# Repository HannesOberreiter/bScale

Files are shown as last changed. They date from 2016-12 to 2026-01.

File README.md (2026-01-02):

# bScale for app.btree.at

Small Arduino project for a DIY beehive scale, with SIM900 for connection to webservice. This project is made to work with the webapplication **[btree.at](https://www.btree.at/)**, an online database for beekeeper but you can use any webservice you want.

## New improved build from Piotr from Poland

Update: 2021-01-29, Piotr did again an update. His setup and code now includes a thermal compensation for drift of weight scale due to shift of temperature, see open issue for more details [issues/7#issue-796765492](https://github.com/HannesOberreiter/bScale/issues/7#issue-796765492) and new ino file: [piotr_SHTC3.ino](arduino/piotr_SHTC3.ino).

***Please see following markdown with description of a improved build version for the beescale:
[Piotr BeeScale](PiotrBeeScale.md).***

Big chances are the separation of the battery unit from the UNO and SIM module and a higher voltage battery storage and solar charging in mind.

Thanks to [@PiotrBeeScale](https://github.com/PiotrBeeScale)

### Hardware

* UNO R3 MEGA ([AliExpress ca. € 2.70](http://de.aliexpress.com/item/high-quality-UNO-R3-MEGA328P-for-Arduino-UNO-R3-NO-USB-CABLE/32350449393.html))
* SIMCON SIM900 Shield (Important with power up pin!) ([Ebay China € 21.99](http://www.ebay.at/itm/SIMCOM-SIM900-Quad-band-GSM-GPRS-Shield-Development-Board-for-Arduino-/231857925209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))
* atTiny85 + Base ([Ebay ca. € 6,00 ](http://www.ebay.at/itm/3x-Atmel-ATTiny85-20PU-und-3x-DIL-Sockel-/251833156761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))
* N-Mosfet ([Ebay ca. < € 1,00](http://www.ebay.at/itm/5-BUZ11-Fairchild-MOSFET-Transistor-50V-30A-75W-0-04R-854773-/311597076091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))
* HX711 Sensor ([Ebay China < € 1,00](http://www.ebay.at/itm/5PCS-Weighing-Sensor-AD-Module-Dual-channel-24-bit-A-D-Conversion-HX711-Shieding-/272298400315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))
* < 200kg platform load cell ([AliExpress ca. € 17,00](http://de.aliexpress.com/item/1PCS-X-100KG-150KG-electronic-platform-scale-load-cell-pressure-balanced-cantilever-load-weight-sensor/1743007676.html))
* LPDP 5V ([Ebay ca. € 1,00](http://www.ebay.at/itm/LP2950CZ-5-0-LowDrop-Spannungsregler-5V-0-1A-TO92-/112028436978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))

and battery case, batteries, resistors, jumper wire, scale plattform, Total cost was under € 100,00.

### Dirty Build:
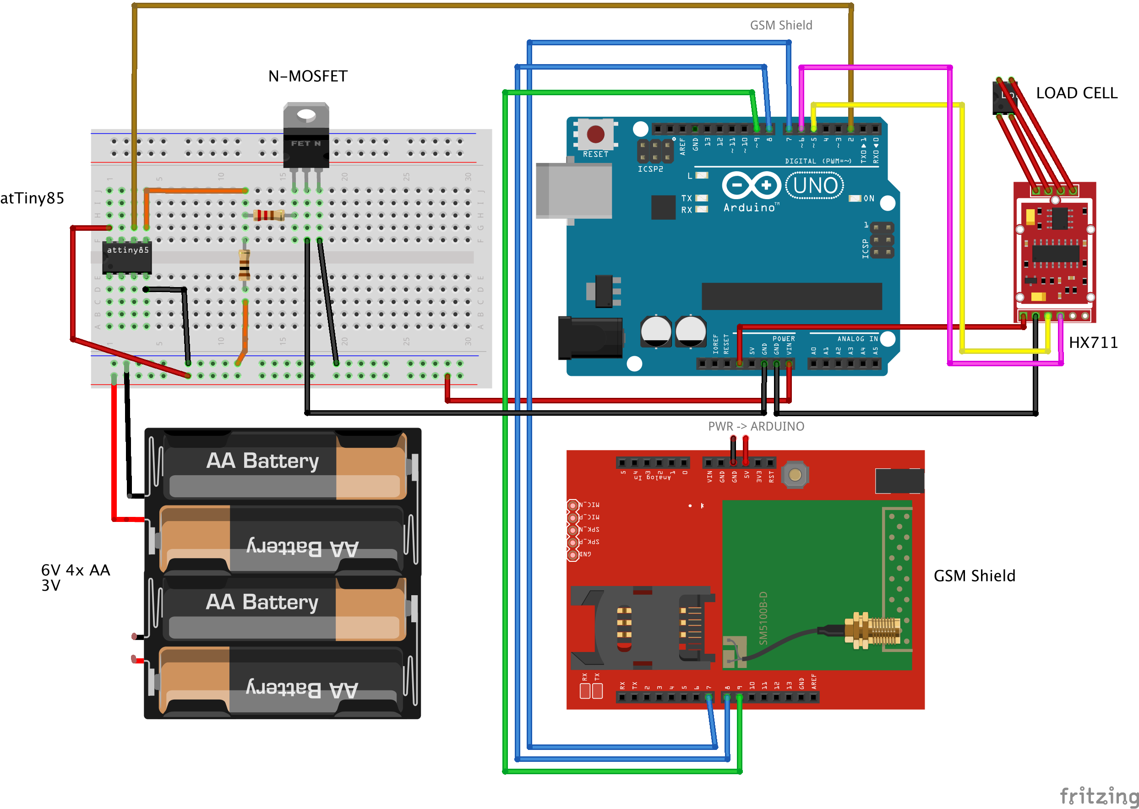
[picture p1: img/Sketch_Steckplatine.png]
Fritzing Sketch Fritzing


### How does / should it work?

UNO will collect data from sensors and send them to the shield. Uno forwards the data to SIM900, which connects to the webservice.
atTiny85 is a simple counter, it will send each 120 minutes a pulse to the N-Mosfet gate. The Mosfet will open circuit to activate Uno.

The UNO will tell the atTiny85 when the sending was completed. If the sending is not completed within 60 seconds, the atTiny will shutdown the UNO even it is not completed (No connection to internet etc.).

### Sensor Reading

For the Sensor reading you need to install the DHT Library and because a bug in Version 1.3 in this library you also need to install the [Adafruid Unified Sensor Library.](https://cloud.githubusercontent.com/assets/181073/21481640/5e14ebd8-cb6a-11e6-972e-c4b4efda6ad1.png)

### The webservice

You can send the data to the beekeeping application (not free) [btree.at](https://www.btree.at/). There the data will be shown in tables and statistics. But you can change the webservice to any you want.

### Videos

**German:**

* [b.tree Open Source Bienenstockwaage kalibrieren ](https://www.youtube.com/watch?v=fo4yXhe6Qlo)
* [b.tree Open Source Bienenstockwaage atTiny85 programmieren ](https://youtu.be/5xHgviWt0F4)

### Images (more in img folder!)

**SIM900 Power On Pin**

On some SIM900 Modules the power up pin is not connected and you need to smolder the right position. Please see your specific Module description.
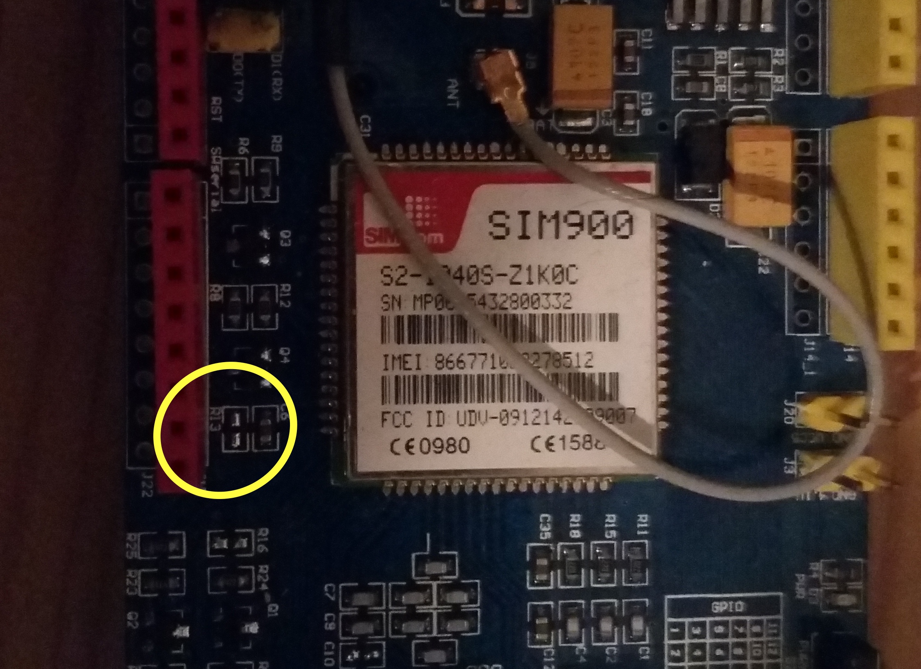
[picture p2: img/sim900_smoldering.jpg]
SIM900 smoldering


If you use a single weight cell like me, the whole build is a little bit "shaky". To prevent to much bending on the iron bars I added this screws on all four sides with just milimeters of space.
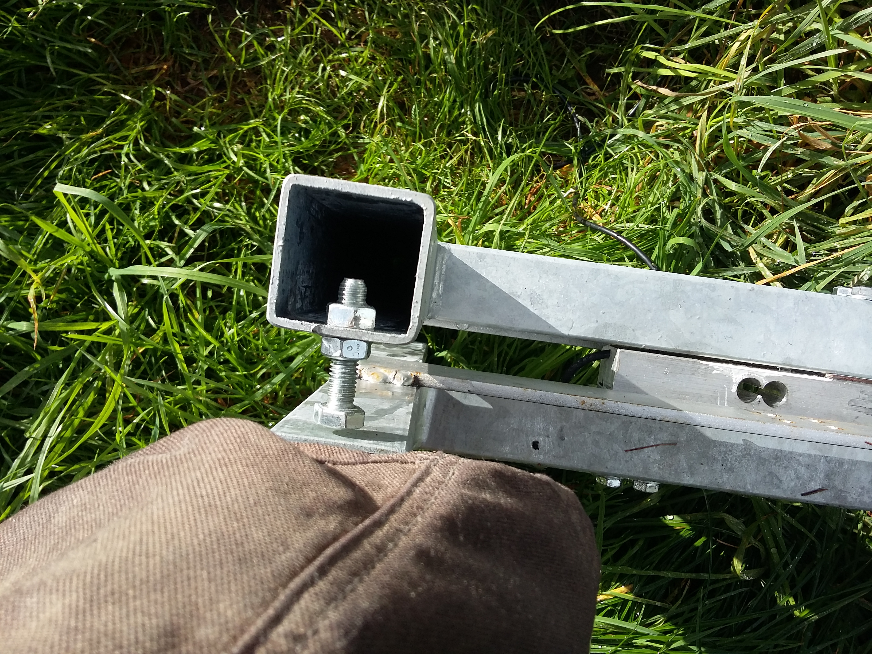
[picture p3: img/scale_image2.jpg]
Screws


### Special thanks to

Andi_H from bienenforum.com for the idea and lots of code pieces

bodge awesome HX711.h library <https://github.com/bogde/HX711>

Nathan Seidle SparkFun Electronics for calibrate code <https://github.com/sparkfun/HX711-Load-Cell-Amplifier>

My father for help with the electronics.

### Tests

* 2016-08-30 First field test the battery would handle 10 days. With each 30 minutes open the mosfet for 1 minute. Changed the code to only open the gate each 2 hours and the UNO will tell the atTiny when it is finsihed. Lets see how much of an improvment this will give us. Upload works fine, data also seems ok, Hannes.
* 2016-10-18 Second field test, with the new code (each 2 hours) did the battery last for 50 days. The battery still has power but not enough to open the GSM connection. I will try now instead of alkaline batteries lithium batteries. They should work better with the spike of energy needed for the GSM connection

### License
GNU GPLv3

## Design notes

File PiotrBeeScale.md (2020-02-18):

# Introduction

This version is a improved build of the bee scale, thanks to Piotr. 

He uses a 5V battery with solar charging in mind and separated the whole battery part from the Arduino and SIM Module for a more safety and cleaner build. 

Following is his build description. 

# Sample weight frame

It was made of a closed profile with a 30x30 mm square section. The weight sensor mounting place was made of a flat bar with a 4 mm diameter. The whole is welded with a MIG / MAG welder. In the lower part of the frame four M8 nuts are welded. Leveling feet are screwed into these nuts. The fastening of the hermetic boxes was made of a cold-bent angle 20x20x2 mm. There is a gap of about 15 mm between the weight segments. The gap is sufficient. The whole was painted with anti-corrosive paint. The frame dimensions have been chosen for the Dadant beehive type.

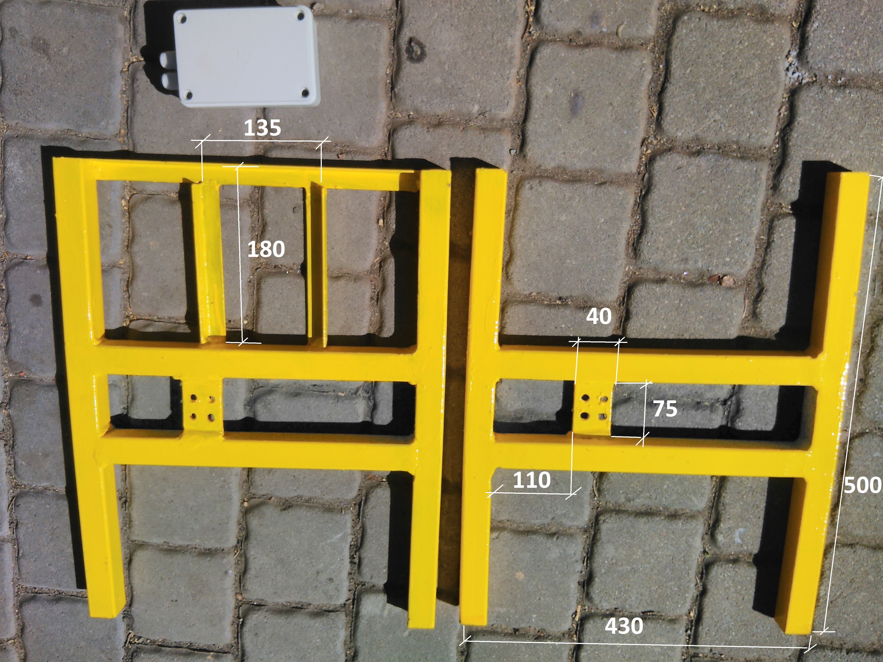
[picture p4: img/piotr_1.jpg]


# View of the scale with mounted hermetic electric boxes
View of the scale with mounted hermetic electric boxes.
Two hermetic electrical boxes were mounted on the frame of the frame. You can use double-sided adhesive tape for this. One has an arduino, mounting plate, HX711 chip, SIM900 and internal antenna. The other has a 6V battery and a solar charging system. Cables enter the boxes through PG-7 glands.

Hermetic electric box, type: S-Box 216 - 120x80x50 - IP65

The weight sensor was attached to the frame with M8x35 mm Allen screws on washers.

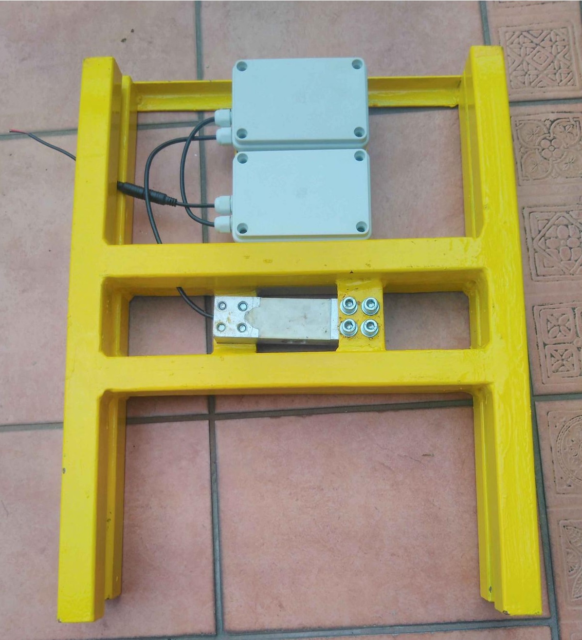
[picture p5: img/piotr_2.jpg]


# Arrangement of elements in electrical boxes

1. Board with HX-711 chip. Fastened to the side wall with double-sided adhesive tape.
2. Arduino Uno R3 board
3. Mounting plate - "Proto Screw Shield Assembled Prototype Terminal Expansion Board Module For Arduino IO I / O UNO R3 MEGA2560 Double Side SMT Solder"
4. Internal antenna for SIM900 - "WIFI 2.4G 3dbi PCB Antenna IPX IPEX WLAN Laptop Bluetooth Zigbee Wireless Module SIM900"
5. SIM900 direct power supply - "2.1mm x 5.5mm Male Plug Right Angle L Jack DC Power Connector"
6. input for power supply from solar panel - "5.5x2.1mm Plug DC male or Female Cable Wire Connector"
7. battery voltage regulator - "LM2596S DC-DC LM2577S Step Up Down Boost Buck Voltage Power Converter Module Non-isolated Constant Current Board 15W 3A"
8. AGM gel battery:
* Voltage: 6V
* Capacity: 1.3Ah
* Height - 51mm
* Length - 96mm
* Width - 24mm

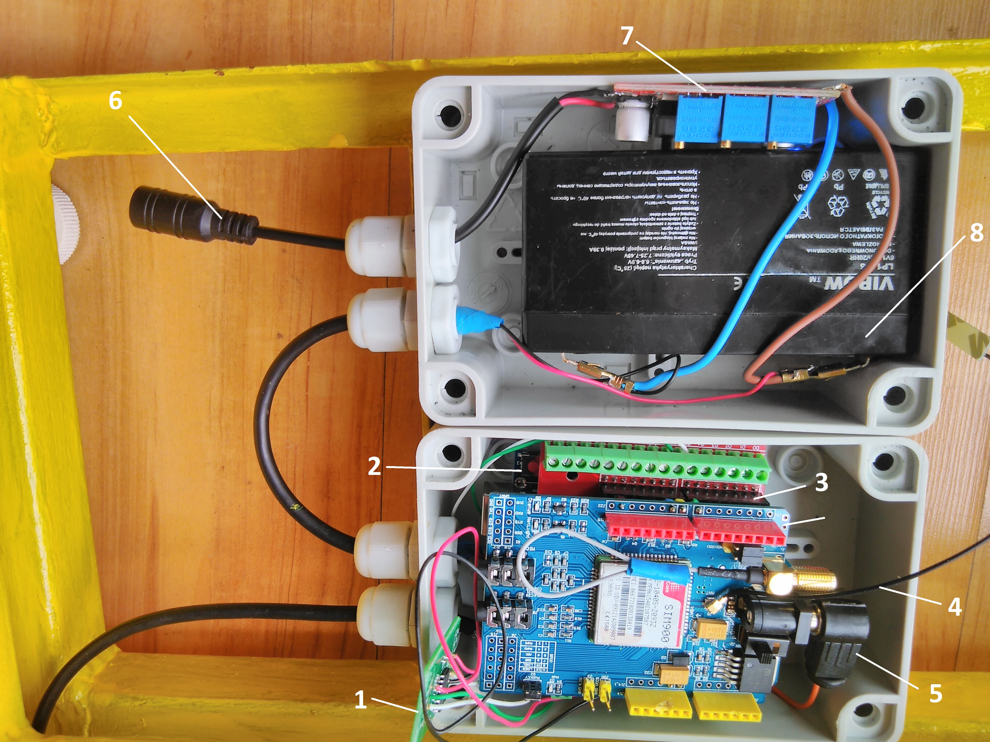
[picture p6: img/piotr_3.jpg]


# Screw Shield

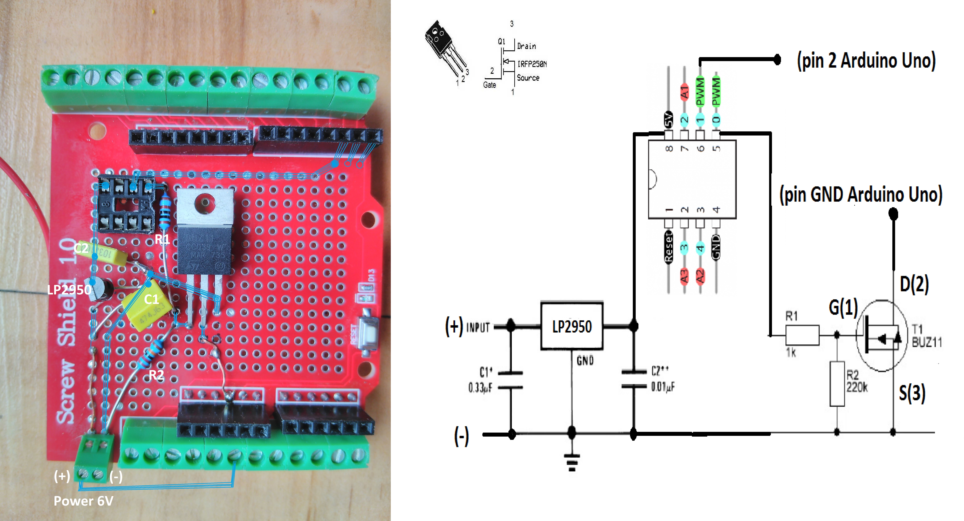
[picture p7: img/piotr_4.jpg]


# SIM900 plate - extra pins

1, 2 - Pins that need to be soldered to the SIM900 board

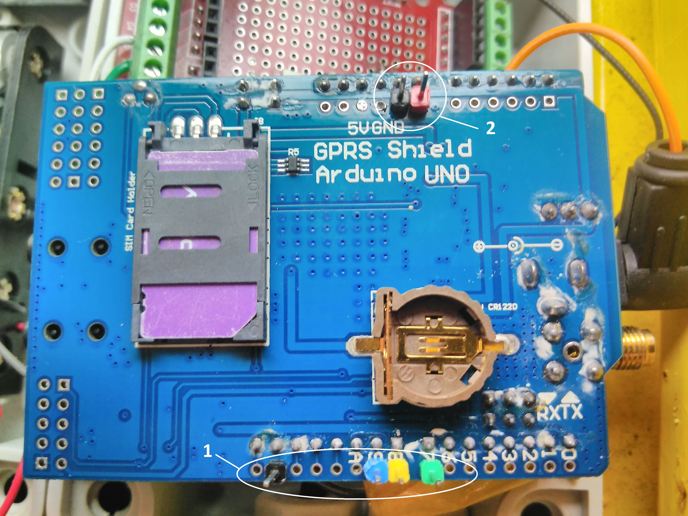
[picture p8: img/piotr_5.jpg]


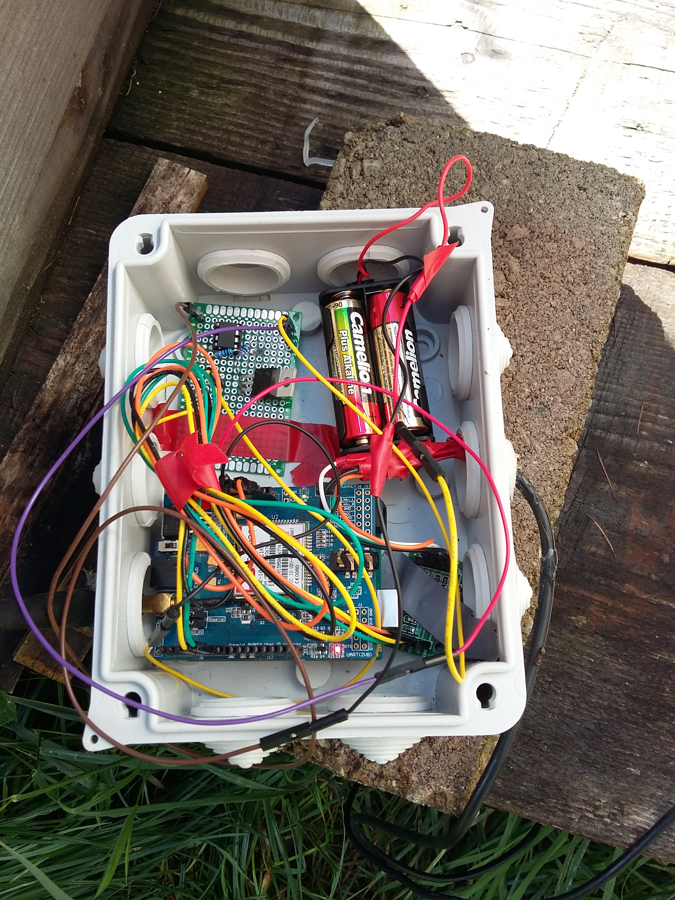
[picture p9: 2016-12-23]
img/scale_image4.jpg

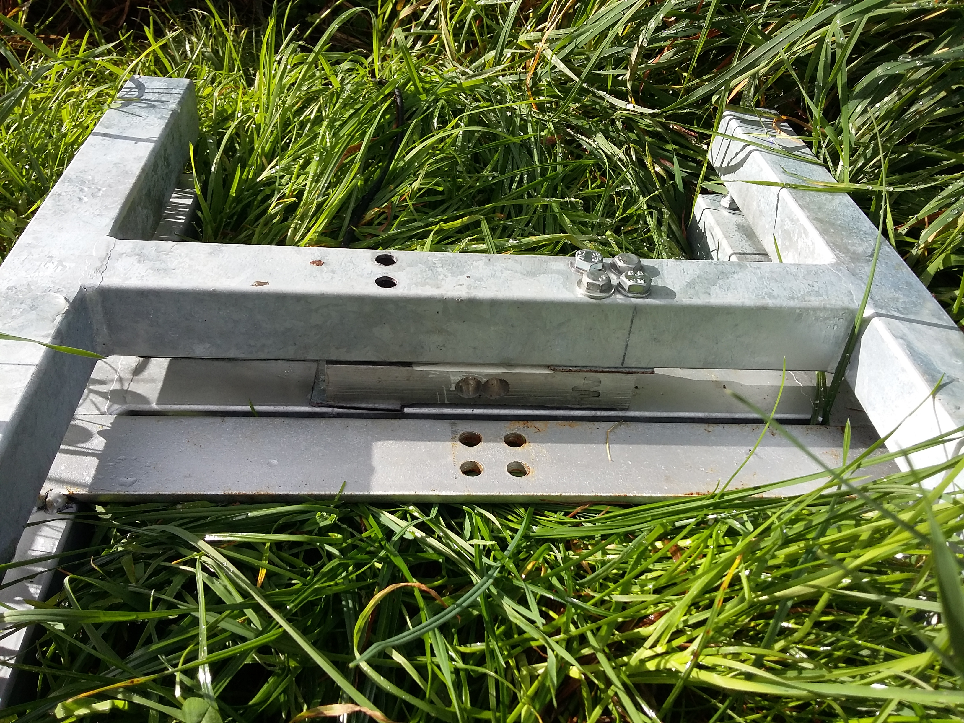
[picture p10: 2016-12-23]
img/scale_image1.jpg

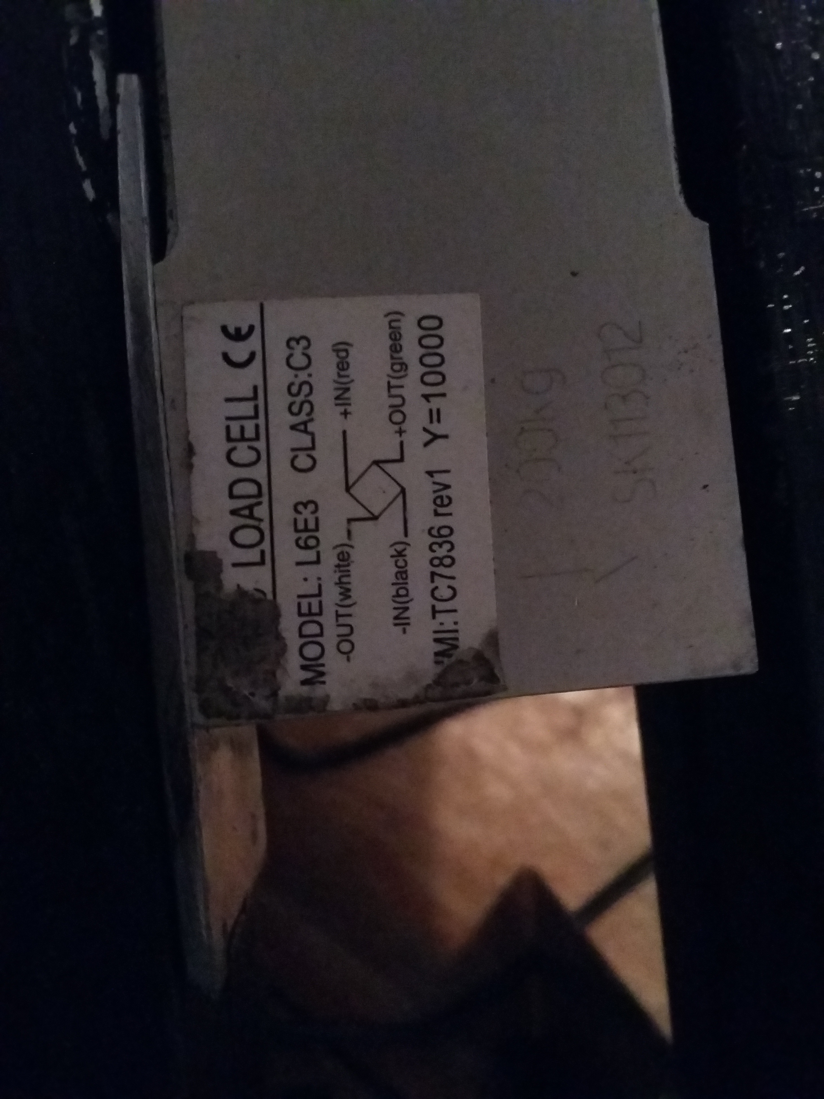
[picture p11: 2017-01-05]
img/load_cell_wires.jpg

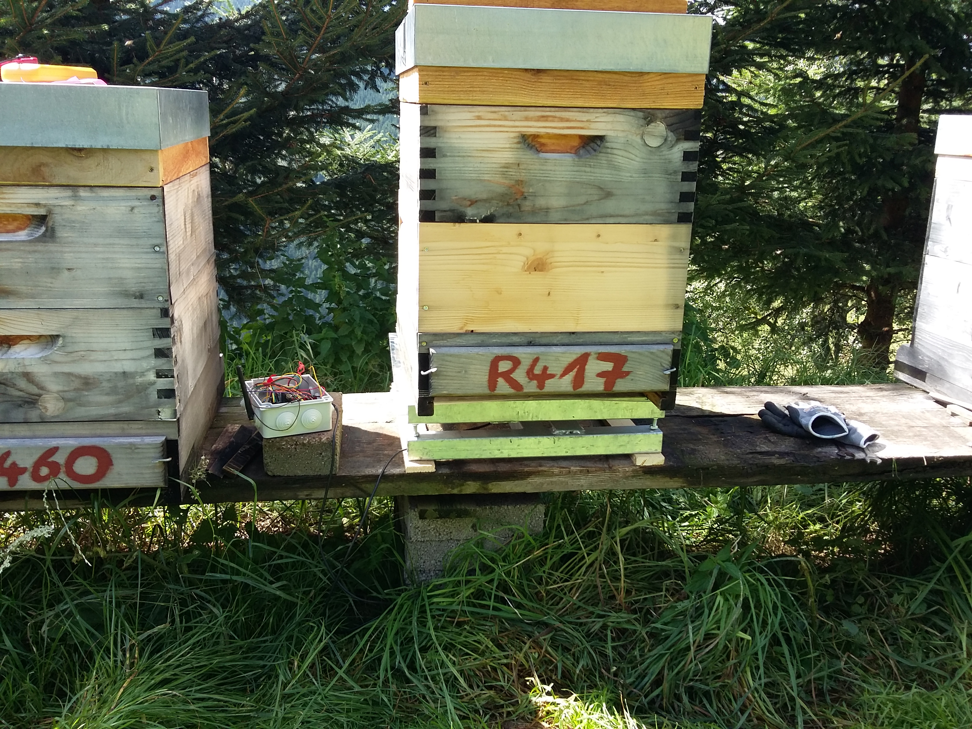
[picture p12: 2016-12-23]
img/scale_image3.jpg

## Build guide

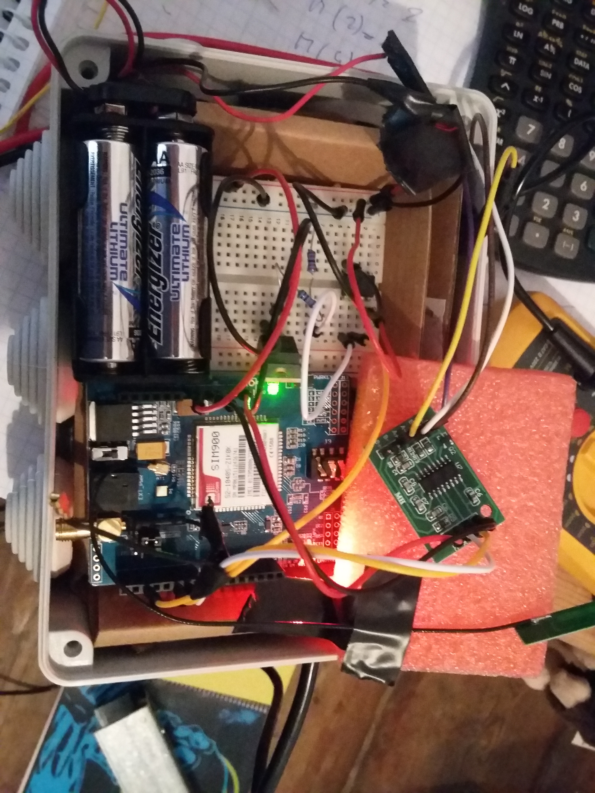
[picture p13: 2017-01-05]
img/inside_build.jpg

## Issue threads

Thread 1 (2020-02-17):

Sample weight frame

PiotrBeeScale, 2020-02-17:
Sample weight frame.
It was made of a closed profile with a 30x30 mm square section. The weight sensor mounting place was made of a flat bar with a 4 mm diameter. The whole is welded with a MIG / MAG welder. In the lower part of the frame four M8 nuts are welded. Leveling feet are screwed into these nuts. The fastening of the hermetic boxes was made of a cold-bent angle 20x20x2 mm.
There is a gap of about 15 mm between the weight segments. The gap is sufficient. The whole was painted with anti-corrosive paint.
The frame dimensions have been chosen for the Dadant beehive type.

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

Closed 2020-02-18.

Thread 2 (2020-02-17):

View of the scale with mounted hermetic electric boxes

PiotrBeeScale, 2020-02-17:
View of the scale with mounted hermetic electric boxes.
Two hermetic electrical boxes were mounted on the frame of the frame. You can use double-sided adhesive tape for this. One has an arduino, mounting plate, HX711 chip, SIM900 and internal antenna. The other has a 6V battery and a solar charging system. Cables enter the boxes through PG-7 glands.
Hermetic electric box, type: S-Box 216 - 120x80x50 - IP65
The weight sensor was attached to the frame with M8x35 mm Allen screws on washers.

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

Closed 2020-02-18.

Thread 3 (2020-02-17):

Arrangement of elements in electrical boxes

PiotrBeeScale, 2020-02-17:
1 - Board with HX-711 chip. Fastened to the side wall with double-sided adhesive tape.
2 - Arduino Uno R3 board
3 - Mounting plate - "Proto Screw Shield Assembled Prototype Terminal Expansion Board Module For Arduino IO I / O UNO R3 MEGA2560 Double Side SMT Solder"
4 - Internal antenna for SIM900 - "WIFI 2.4G 3dbi PCB Antenna IPX IPEX WLAN Laptop Bluetooth Zigbee Wireless Module SIM900"
5 - SIM900 direct power supply - "2.1mm x 5.5mm Male Plug Right Angle L Jack DC Power Connector"
6 - input for power supply from solar panel - "5.5x2.1mm Plug DC male or Female Cable Wire Connector"
7 - battery voltage regulator - "LM2596S DC-DC LM2577S Step Up Down Boost Buck Voltage Power Converter Module Non-isolated Constant Current Board 15W 3A"
8 - AGM gel battery:
• Voltage: 6V
• Capacity: 1.3Ah
• Height - 51mm
• Length - 96mm
• Width - 24mm

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

Closed 2020-02-18.

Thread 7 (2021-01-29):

Thermal compensation of the measurement

PiotrBeeScale, 2021-01-29:
The temperature influences the balance indications. When the temperature changes, the weight reading changes, even though the load on the scale has not changed.
Therefore, temperature measurement and balance reading compensation are required.
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
Need to install a temperature sensor. I chose SHTC3.
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
Library:
https://www.14core.com/wiring-sensirion-i2c-shwx-shtcx-sht3x-temperature-humidity-sensor/

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

**Wiring sketch**
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

The comparison of the temperature and weight measurements shows that the correction is possible with a linear function y=ax+b.
Here is an excel sheet with measurements and a calculated correction.
[Kompensacja temperaturowa.xlsx](https://github.com/HannesOberreiter/bScale/files/5893111/Kompensacja.temperaturowa.xlsx)
**Arduino code changes :**

[Arduino_SHTC3.zip](https://github.com/HannesOberreiter/bScale/files/5893196/Arduino_SHTC3.zip)

HannesOberreiter, 2021-01-29:
Hi Piotr,

hope you doing well. Added the information for your new setup to the repo. I leave the Issue open for others to look at.

I stopped working with hive scales, but I'm happy to see that you still work with it.

Cheers
Hannes

PiotrBeeScale, 2021-02-03:
Hello Hannes

I have noticed that you are tackling more serious projects. I am continuing to work on the scale as it has attracted interest on the beekeeping forum. By the way, there was a problem with the effect of temperature on the scale readings. The differences were so significant that a correction had to be worked out. I am pleased that new people have joined the topic. I hope that they will actively participate in the development of this project, the design of which has impressed me. Especially because of the power saving by using ATtiny85. An app for Android and iOS would be useful for this scale.

 Wishing you good health and further success
Piotr

HannesOberreiter, 2021-02-04:
Hello Piotr,

thats good to hear. Yes, scale drift by temperature is often overlooked even in professional sold bee hive scales.

I reduced the amount of colonies, as the last few years I had a really bad harvest (2x lots of melezitose honey). Now I only do beekeeping as hobby anymore and try to find other ways to get some income for living.

As for the App I'm working on making my application open source (rewriting code and remove external proprietary licences). This may help other beekeepers to host their own server and application in combination in combination with their own hive scale, but this project will take at least another year time, as I only can work on it on my free time.

Cheers
Hannes

PiotrBeeScale, 2021-02-07:
Hello Hannes,
It is sad when there are losses in bees due to unfavorable natural conditions.
But seeing how well you write programs, I believe you have no trouble finding a job.
I am not a programmer, I dealt a bit with database administration. I also have a bit of an idea about electronics. Currently, I am developing scripts that analyze data from beekeeping scales so that event notifications are sent to gmail.
I am very glad that you are planning to provide a smartphone application.
Cheers
Piotr

Closed 2021-02-07.

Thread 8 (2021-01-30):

saving the measurement for shipment

Viator325, 2021-01-30:
Its possible to change the cod to:
-do a measurement of weight, temperature itp. on indicated time np. 6 AM and 6PM remeber this score and send one sms with this score on 8 PM ?
What about use RTC time for ardino ?

HannesOberreiter, 2021-01-30:
Hi @Viator325,

as the attiny is the "timer" in this build, it is probably a little bit more difficult to get an exact timing. You could wake up the arduino more often and check a connected RTC timer - if the time is not ready go back to the attiny for the next cycle. Maybe you could rewrite the attiny  and use the attiny as RTC but I'm not sure if it is possible and how accurate the timer would be.

You can change the code to anything you want, but I cannot give you support, as I'm not actively using any hive scales anymore.

Closing this issue as it is a question and not and direct issue.

Cheers
Hannes

Closed 2021-01-30.

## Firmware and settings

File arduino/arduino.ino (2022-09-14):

#include <SoftwareSerial.h>
#include <avr/sleep.h>
#include "HX711.h"
#include "DHT.h"

//Connection PINS to GSM Shield, change if needed
SoftwareSerial mySerial(7, 8);

//Url to btree API, change if you use your own
const char URL[] PROGMEM = "api.btree.at";
const char API[] PROGMEM = "/api/v1/external";
//Resquestb.in Testing Request
//const char URL[] PROGMEM = "requestb.in";
//const char API[] PROGMEM = "YOU_REQUEST_BIN_URL";
//change this constants as needed
const char APN[] PROGMEM = "webaut"; //APN from your provider, given is HOT (Hofer)
const char KEY[] PROGMEM= "ENTER_HERE_YOUR_API_KEY"; //API Key from your profile page https://beta.btree.at/setting/profile/api
const char ACTION[] PROGMEM = "CREATE"; //Use CREATE_DEMO if you just want to check the connection
const char TIMEZONE[] PROGMEM = "Europe/Vienna"; //php timezoneformat, used to save with the correct current date/time

//This is the unique name of your scale, you must first create them on following page https://beta.btree.at/table/scale_data
const char IDENT[] PROGMEM = "ScaleHouse";

//Array Table for our fixed strings
const char * const MARRAY[7] PROGMEM =
{
  APN,
  URL,
  API,
  KEY,
  ACTION,
  TIMEZONE,
  IDENT,
};

//Sensor Data
char weight[7];
//Demo Data
char temp1[6]= "0.00";
char temp2[6] = "0.00";
char rain[6] = "0.00";
char hum[7] = "0.00";

//Code Variables
float helper;
char conv[150];
char postdata[150];
char response[150];

//atTiny Message PIN
#define FINISHED 2 //Tell the atTiny we are finished

//Scale
#define DIGITALOUT  5     //HX711 DT
#define CLOCK       6     //HX711 CKL
HX711 scale(DIGITALOUT, CLOCK);

//ENTER YOUR CALIBRATED DATA HERE
//as example is my first try given, with 200kg load cell and 3.3V calibrated
float SCALE = -19689.35;
long offset = -145680;

//DHT22
#define DHTPIN 10     // what pin we're connected to
#define DHTTYPE DHT22   // DHT 22 

void setup()
{
delay(500);
mySerial.begin(9600);
Serial.begin(9600);

delay(1000);
Power_UP();
delay(2000);
/*if(sendATcommand2("AT+CPIN?", "+CPIN: READY", "NOTHING", 100) == 0) {
    Serial.println(F("Error SIM locked, please unlock SIM"));
  } else {
    Serial.println(F("Good, SIM is unlocked!"));
  }*/
//Serial.println(F("Find provider!"));
//sendATcommand2("AT+COPS?", "OK", "NOTHING", 100);
Serial.println(F("Connecting .... "));
while( sendATcommand2("AT+CREG?", "+CREG: 0,1", "+CREG: 0,5", 1000)== 0 );
Serial.println(F("Setup finished!"));
delay(2000);
Request();
}

void loop()
{
  //Nothing in Loop
}

void Power_UP()
{
  uint8_t answer=0;
  Serial.println(F("Checking if GSM is running ..."));
  answer = sendATcommand2("AT", "OK", "NOTHING", 2000);
  if (answer == 0)
  {
    // power on pulse
    //Serial.println("Starting GSM ...");
    pinMode(9, OUTPUT);
    digitalWrite(9,LOW);
    delay(1000);
    digitalWrite(9,HIGH);
    delay(2000);
    digitalWrite(9,LOW);
    delay(3000);
    // waits for an answer from the module
    while(answer == 0){     // Send AT every two seconds and wait for the answer
      answer = sendATcommand2("AT", "OK", "NOTHING", 2000);
    }
  }
  Serial.println(F("GSM ready!"));
  delay(1000);
  //Print GSM Reciving Strenth
  Serial.println(F("Get access strength .."));
  sendATcommand2("AT+CSQ", "OK", "NOTHING", 1000);
}


int8_t sendATcommand2(char const* ATcommand, char const* expected_answer1, char const* expected_answer2, unsigned int timeout){

    uint8_t x=0, answer=0;
    unsigned long previous;

    memset(response, '\0', 150);    // Initialize the string
    delay(100);
    while( mySerial.available() > 0) mySerial.read();    // Clean the input buffer
    mySerial.println(ATcommand);    // Send the AT command
    x = 0;
    previous = millis();

    // this loop waits for the answer
    do{
        // if there are data in the UART input buffer, reads it and checks for the asnwer
        if(mySerial.available() != 0){
            response[x] = mySerial.read();
            x++;
            if (x >= 150) { //Overflow protection
              Serial.println(response);
              memset(response, 0, 150);    // Initialize the string
              x=0;
            }
            // check if the desired answer 1  is in the response of the module
            if (strstr(response, expected_answer1) != NULL)
            {
                answer = 1;
            }
            // check if the desired answer 2 is in the response of the module
            else if (strstr(response, expected_answer2) != NULL)
            {
                answer = 2;
            }
        }
    }
    // Waits for the asnwer with time out
    while((answer == 0) && ((millis() - previous) < timeout));
    Serial.println(response);
    return answer;
}


void Request()
{
  if(sendATcommand2("AT+SAPBR=3,1,\"Contype\",\"GPRS\"", "OK", "ERROR", 500) != 1) {
    Serial.println(F("#E setting connection to GPRS!"));
    delay(2000);
    Request();
  }

  snprintf_P(conv, sizeof(conv), PSTR("AT+SAPBR=3,1,\"APN\",\"%S\""), (char*) pgm_read_word(&MARRAY[0]));
  if(sendATcommand2(conv, "OK", "ERROR", 500) != 1) {
    Serial.println(F("#E APN!"));
    delay(2000);
    Request();
  }

  if(sendATcommand2("AT+SAPBR=1,1", "OK", "ERROR", 500) != 1) {
    Serial.println(F("#E already attached to GPRS"));
    //return;
  }

  if(sendATcommand2("AT+SAPBR=2,1", "OK", "ERROR", 1000) != 1) {
    Serial.println(F("#E IP!"));
    delay(2000);
    Request();
  }


  /*if(sendATcommand2("AT+HTTPTERM", "OK", "ERROR", 500) != 1) {
    Serial.println(F("#E nothing to terminate"));
    //return;
  }*/



  if(sendATcommand2("AT+HTTPINIT", "OK", "ERROR", 500) != 1) {
    Serial.println(F("#E HTTP!"));
    delay(2000);
    //Request();
  }


  if(sendATcommand2("AT+HTTPPARA=\"CID\",1", "OK", "ERROR", 500) != 1) {
    Serial.println(F("#E BEARER!"));
    delay(2000);
    Request();
  }


  if(sendATcommand2("AT+HTTPPARA=\"REDIR\",1", "OK", "ERROR", 500) != 1) {
    Serial.println(F("#E setting redirect"));
    //return;
  }

  //------------------------------------------------
  //-------------------Sensor Readings--------------
  //------------------------------------------------
  //HX711 definitions
  delay(2000);
  scale.set_scale();
  scale.set_offset(offset);
  scale.set_scale(SCALE);
  delay(2000);

  //Get weight and convert to char
  dtostrf(scale.get_units(5), 0, 2, weight);
  Serial.println(F("Weight:\t"));
  Serial.println(weight);

  //************DHT22 SENSOR****************
  DHT dht(DHTPIN, DHTTYPE);

  dht.begin();

//DHT22 Readings
 delay(2000);
    Serial.println("*********** DHT11 *********");
    float t = dht.readTemperature();
    float h = dht.readHumidity();
  delay(2000);
  
    // Check if any reads failed and exit early (to try again).
    if (isnan(h)) {
      Serial.println("Failed to read from DHT sensor!");
      return;
    }

    if (isnan(t)) {
      Serial.println("Failed to read from DHT sensor!");
      return;
    }

  
  //Get Temperature & Humidity and convert to char
  dtostrf(t, 5, 2, temp1);
  Serial.println(F("Temperature:"));
  Serial.println(temp1);

  dtostrf(h, 5, 2, hum);
  Serial.println(F("Humidity:"));
  Serial.println(hum);
  //------------------------------------------------
  //-------------------Sensor Readings--------------
  //------------------------------------------------


  memset(postdata, '\0', 150);    // Initialize the string
  snprintf(postdata, sizeof(postdata), "weight=%s&temp1=%s&temp2=%s&hum=%s&rain=%s", weight, temp1, temp2, hum, rain);

  snprintf(conv, sizeof(conv), "AT+HTTPPARA=\"URL\", \"http://%S%S/%S%/%S?%S&%s\"", (char*) pgm_read_word(&MARRAY[1]), (char*) pgm_read_word(&MARRAY[2]),  (char*) pgm_read_word(&MARRAY[6]),  (char*) pgm_read_word(&MARRAY[3]), (char*) pgm_read_word(&MARRAY[4]), postdata);
  if(sendATcommand2(conv, "OK", "ERROR", 500) != 1) {
    Serial.println(F("#E URL!"));
    delay(2000);
    Request();
  }

  if(sendATcommand2("AT+HTTPPARA=\"UA\",\"arduino\"", "OK", "ERROR", 500) != 1) {
    Serial.println(F("#E USERAGENT!"));
    delay(2000);
    Request();
  }

  if(sendATcommand2("AT+HTTPPARA=\"CONTENT\",\"application/x-www-form-urlencoded;\"", "OK", "ERROR", 500) != 1) {
    Serial.println(F("#E HTTP Content-Type!"));
    Request();
  }
  //memset(postdata, '\0', 150);    // Initialize the string
  //snprintf(postdata, sizeof(postdata), "HTTP_X_API=%S&ident=%S&timezone=%S&action=%S", (char*) pgm_read_word(&MARRAY[3]), (char*) pgm_read_word(&MARRAY[6]), (char*) pgm_read_word(&MARRAY[5]), (char*) pgm_read_word(&MARRAY[4]));
  //snprintf(conv, sizeof(conv), "AT+HTTPDATA=%d, 20000", strlen(postdata));
  if(sendATcommand2(conv, "DOWNLOAD", "ERROR", 3500) != 1) {
    Serial.println(F("#E prepare sending"));
    delay(2000);
    Request();
  }
  Serial.println(String(postdata));
  if(sendATcommand2(postdata, "OK", "ERROR", 3500) != 1) {
    Serial.println(F("#E POSTING"));
    delay(2000);
    Request();
  }
  /*if(sendATcommand2("AT+HTTPSCONT?", "OK", "ERROR", 3000) != 1) {
    Serial.println("#E READING CONTENT!");
    return;
  }*/
  delay(500);
  if(sendATcommand2("AT+HTTPACTION=1", "NOTHING", "ERROR", 6000) != 0) {
    Serial.println(F("#E EXECUTING POST!"));
    Request();
  }
  delay(3000);
  if(sendATcommand2("AT+HTTPREAD", "OK", "ERROR", 5000) !=1) {
    Serial.println(F("#E READING!"));
    delay(2000);
    Request();
  }

  if(sendATcommand2("AT+HTTPTERM", "OK", "ERROR", 500) != 1) {
    Serial.println(F("#E TERMINATE!"));
    delay(2000);
    Request();
  }

  done();
}


void done(){
    //Shutdown GSM
    pinMode(9, OUTPUT);
    digitalWrite(9,LOW);
    delay(1000);
    digitalWrite(9,HIGH);
    delay(2000);
    digitalWrite(9,LOW);
    delay(3000);

    //Shutdown Scale
    scale.power_down();

    //Tell atTiny we are finished (should disconnect Arduino and following could should be unnessaccery)
    pinMode(FINISHED, OUTPUT);
    digitalWrite(FINISHED,LOW);
    delay(3000);

    //Set Arduino Sleep mode and send to sleep
    set_sleep_mode(SLEEP_MODE_PWR_DOWN);
    sleep_enable();
    sleep_mode();
}

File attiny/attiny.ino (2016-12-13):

#include <avr/sleep.h>
#include <avr/wdt.h>

//Used for Sleep Mode
#ifndef cbi
#define cbi(sfr, bit) (_SFR_BYTE(sfr) &= ~_BV(bit))
#endif
#ifndef sbi
#define sbi(sfr, bit) (_SFR_BYTE(sfr) |= _BV(bit))
#endif

int const pinGate   = 0; //PIN for MOSFET GATE
int const readGate  = 1; //PIN for MOSFET GATE

long const waitTime = 90000;      //How long the mosfet is open, the arduino takes for me atm. around 40 seconds to connect & upload the data

volatile boolean f_wdt  = true;   //Flag to open MOSFET, true is open
volatile boolean f_done = false;  //Flag when open state is done, false is not done
volatile boolean f_setup= false;  //Flag when open pins and set starting time, false is not done

unsigned long startMillis   = 0;  //holds our starting time
unsigned long currentMillis = 0;  //holds the current timestamp in loop
volatile int count;               //count the circles
int const circles = 900;          // Amount of circle till gate will be opened, Watchdog = 8 sec per circle (eg 900 circles around 7200sec / 60 = 120min)

void setup(){
  pinMode(pinGate,INPUT); // set all used port to intput to save power
  pinMode(readGate,INPUT); // set all used port to intput to save power

  count = circles - 1; //Init first circle on power up, so we dont need to wait for full circle to see if it works

  // CPU Sleep Modes
  // SM2 SM1 SM0 Sleep Mode
  // 0    0  0 Idle
  // 0    0  1 ADC Noise Reduction
  // 0    1  0 Power-down
  // 0    1  1 Power-save
  // 1    0  0 Reserved
  // 1    0  1 Reserved
  // 1    1  0 Standby(1)

  /*cbi( SMCR,SE );      // sleep enable, power down mode
  cbi( SMCR,SM0 );     // power down mode
  sbi( SMCR,SM1 );     // power down mode
  cbi( SMCR,SM2 );     // power down mode*/

  setup_watchdog(9); //9 = 8 Seconds, see Setup Watchdog for other values.
}


void loop(){
  if (f_wdt) {  // wait for timed out watchdog / flag is set when a watchdog timeout occurs
    if(count >= circles){
      //Count reached, lets start our MOSFET

      //Start with Setup our PINS and the millis to compare
      if(!f_setup){
        pinMode(pinGate,OUTPUT); //Set Gate as Output
        pinMode(readGate,INPUT_PULLUP); //Set Read Gate to Pullup will LOW when closed and HIGH when open
        startMillis = millis(); //Snapshot of current time
        digitalWrite(pinGate, HIGH); //Output High to MOSFET to open the gate
        f_setup = true; //set setup flag as finished
        delay(1000); //we need this delay because the arduino has an output on all gates on startup, this would make the following digitalRead going LOW on startup
      } else {
        //Setup is finished, lets see if we should stop open the MOSFET
        if(digitalRead(readGate) == LOW){
          //We got a signal, lets start new sleep circle
          f_done = true; 
        }
        currentMillis = millis(); //Our current Millis
        if ((unsigned long)(currentMillis - startMillis) >= waitTime){
            //Timeout time is reached, lets start new sleep circle
            f_done = true; 
        } 
      }
      //If timeoutTime or Signal form Arduino is given start sleep circle and reset variables 
      if(f_done){
        //digitalWrite(pinGate, LOW);
        // set all used port to intput to save power
        pinMode(pinGate,INPUT); 
        pinMode(readGate,INPUT);
        f_setup   =   false;    // reset setup flag
        f_done    =   false;    // reset open circle flag
        count     =   0;        // reset sleep cycle count
        f_wdt     =   false;    // reset watchdog flag
        system_sleep();         // back to sleep little tiny
      }
    } else {
      //Count has not reached Circles yet, just go back to sleep and count up
      count++;          //count up the circle
      f_wdt=false;      // reset watchdog flag
      system_sleep();   // back to sleep little tiny
    }
  }
}


// set system into the sleep state
// system wakes up when watchdog is timed out
void system_sleep() {

  cbi(ADCSRA,ADEN);                    // switch Analog to Digitalconverter OFF, to save power
  set_sleep_mode(SLEEP_MODE_PWR_DOWN); // sleep mode is set here
  sleep_enable();                      // Activate Sleep Mode
  sleep_mode();                        // System sleeps here
  sleep_disable();                     // System continues execution here when watchdog timed out
  sbi(ADCSRA,ADEN);                    // switch Analog to Digitalconverter ON, to be able to use the pins again

}

// Watchdog sleep Mode Function
// 0=16ms, 1=32ms,2=64ms,3=128ms,4=250ms,5=500ms
// 6=1 sec,7=2 sec, 8=4 sec, 9= 8sec
void setup_watchdog(int ii) {
  byte bb;
  int ww;
  if (ii > 9 ) ii=9;
  bb=ii & 7;
  if (ii > 7) bb|= (1<<5);
  bb|= (1<<WDCE);
  ww=bb;
  MCUSR &= ~(1<<WDRF);
  // start timed sequence
  WDTCR  |= (1<<WDCE) | (1<<WDE);
  // set new watchdog timeout value
  WDTCR  = bb;
  WDTCR  |= _BV(WDIE);
}

// Watchdog Interrupt Service / is executed when  watchdog timed out
ISR(WDT_vect) {
  f_wdt=true;  // set global flag
}

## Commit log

2016-07-03 Added Sketch Files, Image for HX711 module and scale wires, updated readme
2016-07-08 fixed calibrate to work easier
    [calibrate.ino]
2016-08-09 Changed Readme, fixed float to char inside arduino code, reworked calibrate code (start with false on scale and calibrate)
    [arduino.ino, calibrate.ino]
2016-08-09 Made fritzing
    [Sketch.fzz]
2016-08-10 Changed Demo data to Zero, Fixed Endless loop in HTTPINIT if connection is already there. Fixed leading Zeros in dtostrf CHAR*
    [arduino.ino]
2016-08-10 Added to Calibrate my DEMO calibrations, this may help user to understand it better
2016-08-10 Sketch fixes
    [Sketch.fzz]
2016-08-10 Fixed Drawings
    [Sketch.fzz]
2016-08-10 Moved Setup for HX711 to the sensor readings, gives me more accurate data and added power_down() to scale to save even more per
2016-08-19 Added delay before reading sensors, seems to work better.
2016-08-30 Changed atTiny to only open the N-Mosfet for 45 seconds, should be enough. Also now the atTiny only starts the arduino each two hours. Should also be enough.
2016-08-30 PIN1 INPUT_PULLDOWN, waits for OUTPUT arduino on this PIN to exit earlier the while loop
2016-08-30 Updated Sketch
    [Sketch.fzz]
2016-08-31 Arduino now tells atTiny when he is finished (DPIN2 on Arduino TO PIN1 on atTiny)
2016-09-01 Fixed some code and added delay after setup, because arduino has a short time output on his pins when booting.
    [attiny.ino]
2016-09-01 Change again a little bit the delays on arduino
2017-01-01 Updated sketch with LPDP module, now we use the 5V pin not VIN on Arduino UNO. Changed Readme
    [Sketch.fzz]
2017-01-05 Changed Sketch and Added new Images in Image Folder
    [Sketch.fzz]
2017-08-10 Fixed Bug in Sketch, thx to lefteris papadakis
    [Sketch.fzz]
2017-08-10 Added DHT Sensor Reading thx lefteris papadakis
2022-09-14 Update arduino.ino
    sketch of new api url and logic for version 6.x
